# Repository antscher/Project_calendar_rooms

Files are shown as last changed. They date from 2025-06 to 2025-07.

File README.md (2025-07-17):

# Room Calendar Management System

## Project Overview
The Room Calendar Management System is a modern solution for managing meeting room availability using IoT devices. The system combines hardware displays mounted outside each room with a centralized software management platform.

## Project Goals
- Eliminate double-bookings and confusion around room availability
- Provide real-time room status information
- Reduce energy consumption with e-ink displays
- Enable easy room booking directly from the display (by Qr code) or web interface
- Integrate with existing calendar systems

## System Architecture

### Hardware Components
1. **Room Displays**
   - ESP32-S2 microcontroller
   - Waveshare E-ink display
   - Non - Rechargeable battery system
   - QR code for booking

2. **Server Infrastructure**
   - Central management server
   - WiFi network integration

### Software Components
1. **Backend System**
   - Room management
   - Booking system
   - User authentication
   - Calendar integration

2. **Frontend Interfaces**
   - Web dashboard for administrators
   - Display interface for e-ink screens

## Key Features
- Real-time room availability display
- Direct booking from room displays
- Low-power operation with years of battery life
- Calendar synchronization
- Administrative dashboard

## System Illustrations

### Example Screens and Interfaces

#### Calendar Example
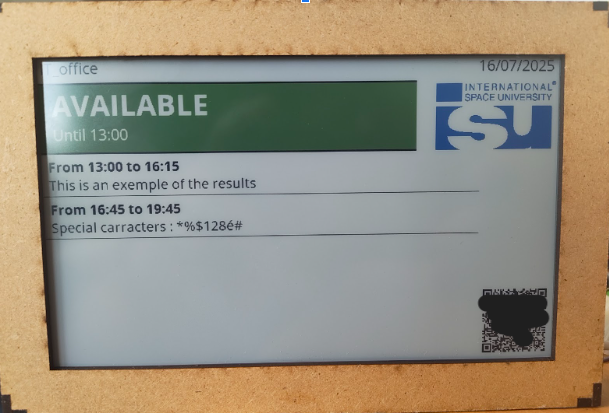
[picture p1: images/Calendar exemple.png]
Calendar Example


#### Reserved Calendar Example
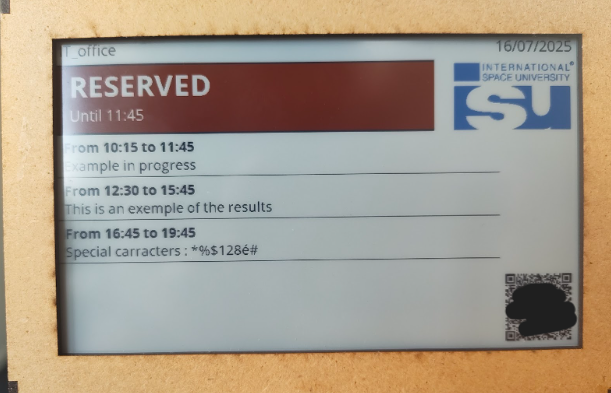
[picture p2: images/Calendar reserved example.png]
Reserved Calendar Example


#### On Air Screen
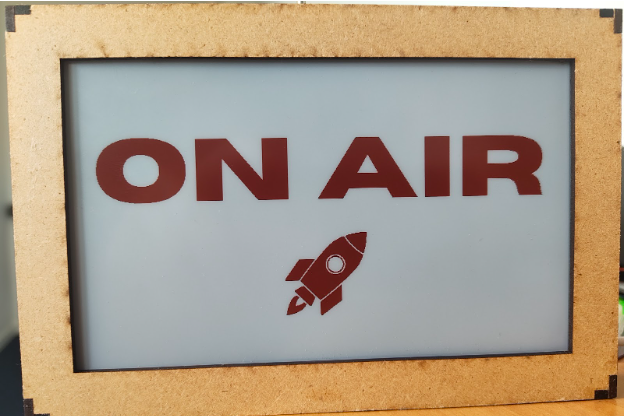
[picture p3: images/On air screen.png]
On Air Screen


#### Mosquitto Server Control
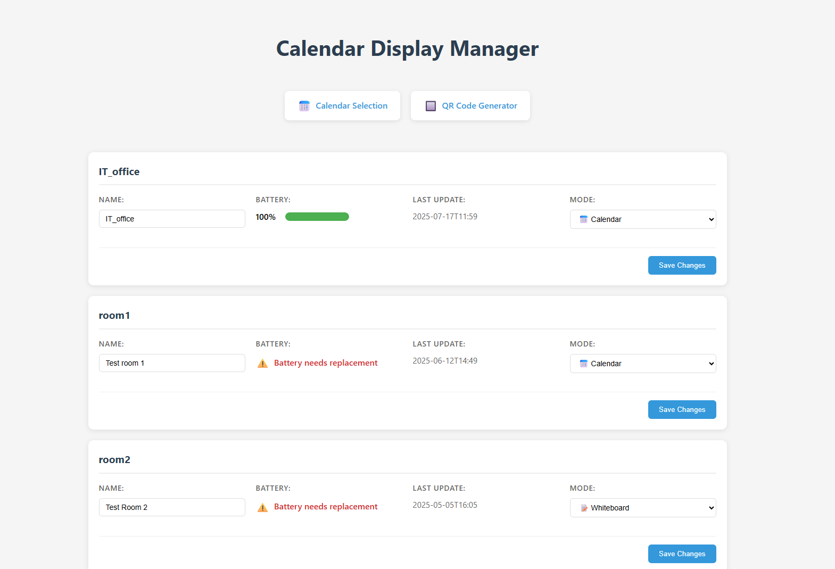
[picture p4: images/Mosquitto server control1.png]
Mosquitto Server Control


## Expected Benefits
- Improved room utilization
- Reduced booking conflicts
- Enhanced user experience
- Energy-efficient operation

## Project Structure
```
Project_calendar_rooms/
├── code_esp32/                      # ESP32 firmware and related tools
|   ├── font2bytes-dynamics/         # Tool for converting fonts to byte arrays
│   └── main/                        # Main ESP32 application code
├── Hardware/                        # Hardware design files
│   ├── cadre room V_.svg/           # Display frame design (version _)
│   ├── Support cadre V_.stl/        # Support of the cadre to be print in 3d (version _)
│   └── esp32 room pcb/              # Custom PCB design for ESP32
└── code_service_server_python/      # Server-side Python applications
    ├── mqtt_service/                # MQTT broker and message handling service
    └── web_local_consol/            # Local web console for room management
```

## License
This project is licensed under GNU GENERAL PUBLIC LICENSE V3 - see the LICENSE.md file for details.

## Main Contributor
This project was developed by Antoine Scherpereel as part of an intership project at ISU (International Space University).

For questions or support, contact:
- Antoine Scherpereel
- Email: antoine.scherpereel@isunet.edu

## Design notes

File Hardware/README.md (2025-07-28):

# Hardware Components Selection

## ESP32-S2 Microcontroller : ESP32-S2 pico from waveshare
Here the link : https://www.waveshare.com/esp32-s2.htm
- **Why this choice?**
  - Built-in WiFi capabilities for network connectivity
  - Low power consumption with deep sleep modes
  - Sufficient GPIO pins for e-ink display interface
  - Cost-effective solution for IoT applications
  - Native USB support for easy programming
  - Enough RAM for rendering the image before displaying it

  Can be power supply between 10V and 1.8V theorically in reality it is needed to be superior to 2.65V

## Waveshare E-Ink Display : Spectra 7.3" from Waveshare
Here the link : https://www.waveshare.com/7.3inch-e-paper-hat-e.htm 
- **Why this choice?**
  - Ultra-low power consumption - only uses power when refreshing
  - Excellent readability in various lighting conditions
  - Maintains display without power
  - Available SPI interface for easy integration with ESP32
  - 6 colors 

## Battery Selection : Roomz display battery
Here the link : https://www.bechtle.com/fr-en/shop/roomz-display-spare-batteries--4329865--p
- **Why not rechargeable Li-primary**
  - High energy density
  - Low self-discharge rate
  - Long cycle life
  - Safe for fire problems

  Normally the battery will stay really close to 3V during all it live cycle but a varation can cause effects.
  Capacity (%)	Voltage (V)
  100%	        3.0 – 3.2 V
  90%	          3.0 – 3.1 V
  80%	          2.95 – 3.1 V
  50%	          2.9 – 3.0 V
  20%	          2.8 – 2.9 V
  10%	          2.7 – 2.8 V
  0%          	~2.0 – 2.5 V

  Note : After testing with different input voltage, the results are : 
  - > 2.65V : work normally
  - between 2.65 and 2.4 : work but risk of losing is SPRAM
  - < 2.4 V : not working at all

  Conclusion : we can use even if we consider there is risk of malfounctionning at the end of life
  (Possibility utilising NVS memory but there is a limit in R/W cycle)

## Power Considerations
- E-ink display only draws power during updates
- ESP32-S2 deep sleep mode < 10µA
- Expected battery life: 2-3 years between replacing battery

## The PCB 

The pcb is made on Kicad
You can open it and modify it with Kicad, may be you will need to downloads some library for footprints
You can purshase it, but you have to first expot in gerber file.
All of the componnent required are in the "Component list.xlsx", you can change some component by similar ones but make sure the footprint is compatible (or modify it).

## The support of the frame

It is made in Fusion 360, you have access to the STL file to print the design.
Use M3 screws to attach it.

## The frame

The frame is made with Inkscape, it is a .svg file.
It is designed for 3mm wood.
It needs to be cut (red lines) and engraved (blue surface).
You need to glue it except the back, which just fits in so you can remove it after.
For the screen, tape it or glue it.

### Frame Images

See the following images for reference:
- Frame closed
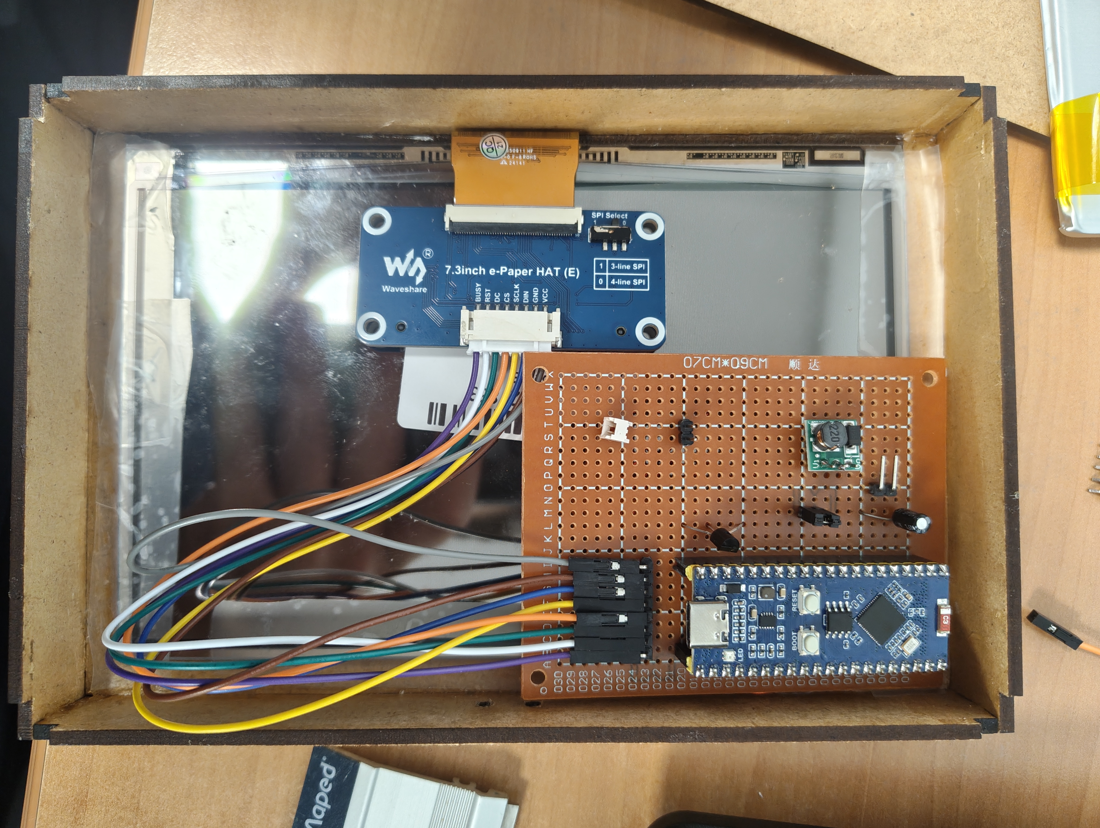
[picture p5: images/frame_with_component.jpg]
Frame component
-

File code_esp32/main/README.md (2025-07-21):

## Overview
An ESP32-based e-paper display system for room availability and scheduling. This system connects to WiFi, communicates via MQTT, and displays room booking information on a Waveshare 7.3" e-Paper display.

## Directory Structure
```
main/
├── src/
│   ├── Config/         # Configuration files
│   ├── e-Paper/       # E-paper display drivers
│   ├── Fonts/         # Font definitions
│   ├── GUI/           # Graphics interface
│   └── Image/         # Image resources
├── calendar.cpp       # Calendar logic implementation
├── calendar.h         # Calendar class definitions
├── interface_graphique.cpp  # Display interface
├── interface_graphique.h    # Display definitions
├── main.ino          # Main program
├── mqtt_communication.ino    # MQTT handling
└── wifi_data.h       # WiFi credentials (to be created)

```
src/ is the library from https://www.waveshare.com/wiki/7.3inch_e-Paper_HAT_(E)_Manual#ESP32.2F8266 -> demo code but it is modified to use dynamics fonts and all of the ASCII characters table

## Setup Instructions

### 1. Create wifi_data.h
Create a new file `/main/wifi_data.h` with your network credentials:

```cpp
#ifndef WIFI_DATA_H
#define WIFI_DATA_H

const char* ssid = "YOUR_WIFI_SSID";
const char* password = "YOUR_WIFI_PASSWORD";
const char* mqtt_broker = "YOUR_MQTT_BROKER_ADDRESS";
const int mqtt_port = 1883;
const String client_id = "esp32-client-XXXX"; 

// Unique client ID
const char* mqtt_username = "YOUR_MQTT_USERNAME";
const char* mqtt_password = "YOUR_MQTT_PASSWORD";
const char* topic = "room/ROOM_NAME";
const char* topic_reponse = "resp_room/ROOM_NAME";

// Variable of referency
const char name_room_const[] = "ROOM_NAME TO DISPLAY";

#endif
```

### 2. Hardware Requirements
- ESP32-S2 microcontroller
- Waveshare 7.3" e-Paper display
- See Hardware/README.md for detailed specifications

### 3. Software Dependencies
Install this librairies if needed 
- Arduino IDE with ESP32 by espressif in the board manage (especially ESP32 S2 Dev Module) (tested v3.2.0)
- Required Libraries:
  - PubSubClient (tested v2.8)
  - WiFi (built in)
  - SPI (built in)

### 4. Building and Flashing
1. Open the project in Arduino IDE
2. Select ESP32-S2 Dev Module board
3. Install required libraries
4. Compile and upload to ESP32 with parameters of esp 32 as : 
- USB CDC on boot : "Enabeled"
- CPU frequency : "160MHz"
- Core debug "None"
- Erase all flash : "Enabeled" (or "Disabled" for saving NVS memory)
- Flash frequency : "40 MHz"
- Flash Mode : "QIO"
- JTAG Adapter : "Disabeled"
- USB Firmware MSC : "Huge APP (3MB No OTA/1 MB SPIFFS)"
- PSRAM : "Enabeled"
- Upload Mode "UART0"
- Upload Speed : "921600"
- Zigbee Mode : "Disabeled"

## Operation Modes
- **Normal Mode**: Displays room availability and upcoming events
- **Night Mode**: Shows logo and enters deep sleep (20:00-7:00)
- **On Air Mode**: Displays "On Air" sign for broadcasting
- **Error Mode**: Handles connection failures

## MQTT Message Format
Messages follow this structure :
- for a calendar
```
cYYYY-MM-DDTHH:MM[Event1 Description]DD,MM,DD,MM,HH,MM,HH,MM[Event2...]
```
- for other  (the first letter is the screen mode)
```
wYYYY-MM-DDTHH:MM
```
First character indicates mode:
- 'c': Calendar mode
- 'w': White screen (or night mode)
- 'o': On Air mode
- 'e': Error
- 'u': Update room name

## Power Management
- Uses deep sleep between updates
- Wakes up for:
  - Scheduled updates
  - Event start/end times
  - Daily morning activation

## Memory Optimization

To maximize battery life and reliability, the ESP32 firmware now uses RTC memory (`RTC_DATA_ATTR`) to store key variables such as `name_room` and `new_day`. This allows the device to retain these values even during deep sleep cycles, minimizing unnecessary writes to flash and saving power.

- `name_room`: The room name is stored in RTC memory and updated only when needed.
- `new_day`: This variable tracks the battery status and is also stored in RTC memory.

### Battery Reset Procedure

To reset the battery status after a replacement or maintenance:
1. Open the Mosquitto MQTT app.
2. Mode reset battery
3. Press "Save" in the app and then refresh .

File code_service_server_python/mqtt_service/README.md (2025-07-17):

# 📡 MQTT Calendar Service

A Python-based MQTT service by **Antscher** that manages communication between ESP32 devices and Google Calendar.

This service handles:
- MQTT broker communication
- Google Calendar integration
- ESP32 device state management
- Screen mode control

---

## 🚀 Features

- 🔄 **MQTT Communication**  
  Handles bi-directional communication with ESP32 devices.

- 📅 **Google Calendar Integration**  
  Fetches and formats calendar events for display.

- 🔋 **Battery Management**  
  Tracks and stores ESP32 device battery status.

- 🖥️ **Screen Mode Control**  
  Manages different display modes (calendar, whiteboard, on air).

---

## ⚙️ Requirements

- Python 3.7+
- paho-mqtt
- google-api-python-client
- oauth2client
- python-dotenv

## 🛠️ Configuration

1. Set up `.env` file with MQTT broker details
2. Configure `credentials.json` for Google Calendar API
3. Ensure `token.json` is present for OAuth2 authentication

### Environment Variables (.env)

Create a `.env` file with the following configuration:

```properties
# MQTT Broker Configuration
USE_LOCAL=false           # Set to true for local broker, false for remote
BROKER_LOCAL=localhost    # Local broker address
BROKER_IP=your.broker.ip  # Remote broker IP/hostname
PORT=1883                 # MQTT broker port
TOPIC=room/#             # Topic pattern to subscribe to
USERMQTT=your_username   # MQTT authentication username
PASSWORD=your_password   # MQTT authentication password
```

- `USE_LOCAL`: Toggle between local and remote broker
- `BROKER_LOCAL`: Address for local MQTT broker
- `BROKER_IP`: Address for remote MQTT broker
- `PORT`: Port number for MQTT connection
- `TOPIC`: MQTT topic pattern for device communication
- `USERMQTT`: Username for MQTT authentication
- `PASSWORD`: Password for MQTT authentication

## 📁 Project Structure

mqtt_service/
│
├── communication_mqtt.py   # Main MQTT handler
├── google_agenda.py       # Google Calendar integration
├── esp_data.py           # ESP device state management
├── credentials.json      # Google API credentials
├── token.json           # OAuth2 tokens
└── .env                 # Environment configuration

## Stockage of data

Every data are stocked on the "esp-data.json". If you want you can manually change the data or the mode by modifying it. I you want to delete a screen you need to remove the line that correspond  directly on the file

## 🔐 Security
- Secure MQTT credentials
- OAuth2 authentication for Google Calendar
- Local JSON storage for device data

## 🧑‍💻 Author
Made with 🧠 by Antscher

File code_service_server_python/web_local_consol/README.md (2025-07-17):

# 🗓️ Room Control Web App

A local Flask web app by **Antscher** to manage and control multiple calendar-enabled display screens in different rooms.

This app allows you to:
- View info
- Set and update room names
- Assign or change screen display modes
- Configure individual calendar URLs
- Generate and display QR codes for easy mobile access

---

## 🚀 Features

- 📺 **Screen Mode Selector**  
  Choose the display mode for each screen (agenda, standby, status…).

- 🏷️ **Custom Room Names**  
  Easily rename rooms via the web interface.

- 🔗 **Calendar URL Configuration**  
  Assign custom ICS / Google Calendar URLs to each room for event syncing.

- 📱 **QR Code Generator**  
  Automatically generate a QR code for arduino in C++

- 💾 **Data Persistence**  
  All configurations are stored in a JSON file (`esp_data.json`) for consistent behavior after reboot.

---

## ⚙️ Requirements

- Python 3.7+
- Flask
- qrcode
- Pillow

## 🛠️ How It Works
Launch the app:
python app.py

Access the local web interface at:
http://localhost:5000

## 📁 Project Structure

project/
│
├── app.py                 # Main Flask app, entry point for the web server
├── esp_data.json          # JSON database of all ESP screen data and configuration
├── qr_code_generator/     # Python scripts for generating QR codes for ESP devices
│   ├── generate_qr.py     # Main QR code generation script
│   └── ...                # Other helper scripts
├── templates/             # HTML templates for Flask (Jinja2)
│   ├── index.html         # Main dashboard page
│   ├── room_config.html   # Room configuration page
│   └── ...                # Other template files
├── tmp/                   # Temporary storage for generated C++ files and QR images
│   └── ...                # Files created during runtime
└── static/                # Static assets (JavaScript, CSS, images)
    ├── style.css          # Main stylesheet
    ├── script.js          # Main JavaScript file
    └── ...                # Other static files

# Web Local Console

A Flask web application for managing ESP device configurations and calendars.

## Setup

1. Install required packages:
```bash
pip install flask python-dotenv
```

2. Create a `.env` file in the project root with the following variables:
If it don't works, just rename the variable in the script "app.py"
```
USERNAME=your_username
PASSWORD=your_password
DATA_FILE=/path/to/esp_data.json
FLASK_HOST=0.0.0.0
FLASK_PORT=5000
```

## Environment Variables

- `USERNAME`: Authentication username for accessing the web interface
- `PASSWORD`: Authentication password for accessing the web interface
- `DATA_FILE`: Path to the JSON file storing ESP device data
- `FLASK_HOST`: Host address for the Flask server (default: 0.0.0.0)
- `FLASK_PORT`: Port number for the Flask server (default: 5000)

## Running the Application

Start the server:
```bash
python app.py
```

The web interface will be available at `http://<FLASK_HOST>:<FLASK_PORT>`

## Features

- ESP device management and status monitoring
- Calendar configuration and QR code generation
- Basic authentication for secure access

## 🧑‍💻 Author
Made with 🧠 by Antscher

---

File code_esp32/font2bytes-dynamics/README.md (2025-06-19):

# font2bytes (Modified Version)

Python script to create custom fonts for Waveshare e-Paper / e-Ink (ESP32 module)

---

## 📌 About This Fork

This is a modified version of the original [font2bytes](https://github.com/TheHeXstyle/font2bytes) project by [TheHeXstyle](https://github.com/TheHeXstyle), licensed under **LGPL v3.0**.

My contribution introduces **dynamic character widths**:  
🔠 Each character now has its own **individual width** depending on its actual pixel width, instead of a fixed-size grid. This allows more compact and proportional text rendering on e-paper displays.
🔠 Also now all the ASCII characters are implemented (exemple : @)

However, you have to also modify the library of waveshare (there is an example in main in src of this repo)

---

## 🎯 Motivation

The Waveshare ESP32 library only offers a few basic fixed-width fonts (`font8`, `font12`, `font16`, `font20`, `font24`). This is very limiting for UI design or text-heavy applications.

This script helps generate **custom variable-width fonts** using any TrueType font (`.ttf`), with complete control over size and style.

---

## 🧰 Requirements

- Python 3
- [Pillow](https://pillow.readthedocs.io/en/stable/index.html)
- [numpy](https://numpy.org/install/)

> 💡 **Note:** Pillow and PIL cannot co-exist in the same environment. Please uninstall `PIL` before installing `Pillow`.

---

## 🛠️ How to Use

1. Drop any font you want to use (`.ttf`) inside the `./fonts` folder.

2. In `font2bytes.py`, configure:
   - A name for your new font output file
   - The `.ttf` font name you want to use (default: `Roboto-Regular`)
   - The desired height of characters (width is dynamic)

3. Run the script:

   ```bash
   python font2bytes.py

The python script will generate the new .cpp file within the ./output folder with the desired name

within the waveshare library source folder (Arduino\libraries\esp32-waveshare-epd\src)

4. add the new .cpp font file

5. open the fonts.h and

6. add a new "extern" line with the name of the new font

    E.g.: extern sFONT FontBold40;

7. Use the new font in your script and enjoy!

    E.g. Paint_DrawString_EN(5, 0, "waveshare Electronics", &FontBold40, BLACK, WHITE);

Examples
-------------------
within the ./output folder there are already a couple of .cpp files that can be used without running the oython code.
Just follow the instructions from the 6th step

Author
-------------------
Original version by TheHeXstyle

Modified and extended by Antscher to support dynamic character widths

License
-------------------
LGPL v3.0, see LICENSE for details.

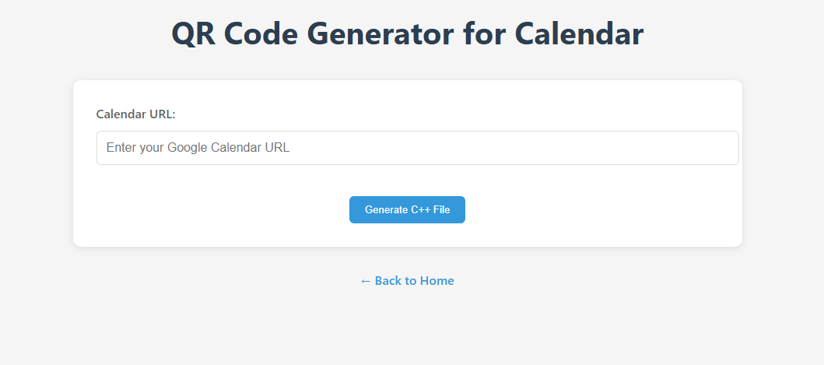
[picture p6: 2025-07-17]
images/Mosquitto server control3.png

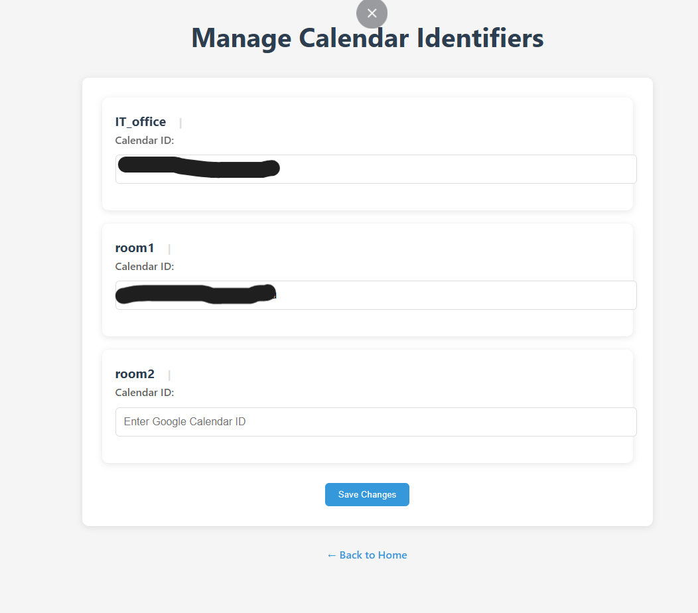
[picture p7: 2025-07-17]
images/Mosquitto server control2.png

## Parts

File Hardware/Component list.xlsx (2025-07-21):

PCB part
Item # | *Designator | *Qty | Manufacturer | *Mfg Part # | Description / Value | *Package/Footprint | Mounting Type | Your Instructions / Notes | *Unit Price(5 sets) | *Total | *Delivery Time | *Actual Purchase Mfg Part # | Customer Reply | PCBWay Update
1 | ESP32S2L1, ESP32S2L2 | 2 | Harwin | M20-7862042 | 20-pin 2.54 mm vertical pin socket | Connector_PinSocket_2.54mm:PinSocket_1x20_P2.54mm_Vertical | SMD | Right & left pin rows for ESP32S2 module | $1.992 | $19.920
2 | J1 | 1 | Harwin (or generic) | PTV1R-08-G-D-K | 8-pin 2.54 mm horizontal pin header | Connector_PinHeader_2.54mm:PinHeader_1x08_P2.54mm_Horizontal | THT | Use PTV1R-08-G (Harwin) or similar quality header | $0.843 | $4.215 |  | M20-9960845
3 | J2 | 1 | Molex (JST equivalent) | 5352 (PH series) or 53048-0210 | 2-pos 1.25 mm PicoBlade right-angle header (battery Conn) | Connector_JST:PicoBlade_53048-0210_1x02_P1.25mm_Horizontal | THT | For battery connector — use Molex 53048-0210 | $0.409 | $2.045 |  | 53048-0210
4 | Q1 | 1 | Alpha & Omega Semiconductors | AO3400A | 30 V N‑Channel MOSFET, SOT‑23 | SOT-23-3 | SMD |  | $0.121 | $0.605
5 | SW1 | 1 | Würth Elektronik | 450301014042 | Slide switch SPDT 500 mA / 12 V, red actuator | Button_Switch_THT:WS-SLTV THT | THT | Use WS‑SLTV series; datasheet | $0.596 | $2.980 |  | SLW-864574-5A-RA-N-D
6 | C1,C2 | 1 | Murata Electronics | GRM21BR61C106KE15K | Capacitor 10uF | C_0805_2012Metric | SMD
7 | L1 | 1 | BOURNS | SRR1260-100M | Inductance 10uH | SRR1260-100M | SMD
7 | L2 | 1 | ANALOG DEVICES | MAX1724EZK50+T | Regulator DC/DC 5V | MAX1724EZK50+T | SMD

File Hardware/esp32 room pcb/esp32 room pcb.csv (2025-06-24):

Reference | Qty | Value | DNP | Exclude from BOM | Exclude from Board | Footprint | Datasheet
ESP32S2L1 | 1 | Left pins |  |  |  | Connector_PinSocket_2.54mm:PinSocket_1x20_P2.54mm_Vertical | ~
Esp32S2L2 | 1 | Right pins |  |  |  | Connector_PinSocket_2.54mm:PinSocket_1x20_P2.54mm_Vertical | ~
J1 | 1 | DISPLAY connector |  |  |  | Connector_PinHeader_2.54mm:PinHeader_1x08_P2.54mm_Horizontal | ~
J2 | 1 | BATTERY connector |  |  |  | Connector_JST:JST_PH_S2B-PH-SM4-TB_1x02-1MP_P2.00mm_Horizontal | ~
Q1 | 1 | AO3400A |  |  |  | Package_TO_SOT_SMD:SOT-23 | http://www.aosmd.com/pdfs/datasheet/AO3400A.pdf
SW1 | 1 | SW_Wuerth_450301014042 |  |  |  | Button_Switch_THT:SW_Slide-03_Wuerth-WS-SLTV_10x2.5x6.4_P2.54mm | https://www.we-online.com/components/products/datasheet/450301014042.pdf

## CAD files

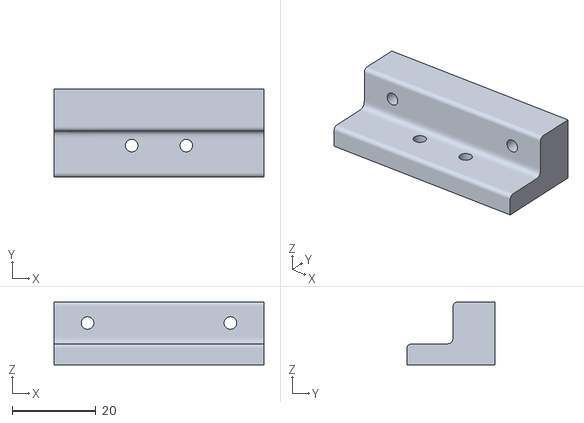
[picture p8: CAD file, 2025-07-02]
Hardware/support cadre V2 v2.stl
50.0 x 21.0 x 15.0

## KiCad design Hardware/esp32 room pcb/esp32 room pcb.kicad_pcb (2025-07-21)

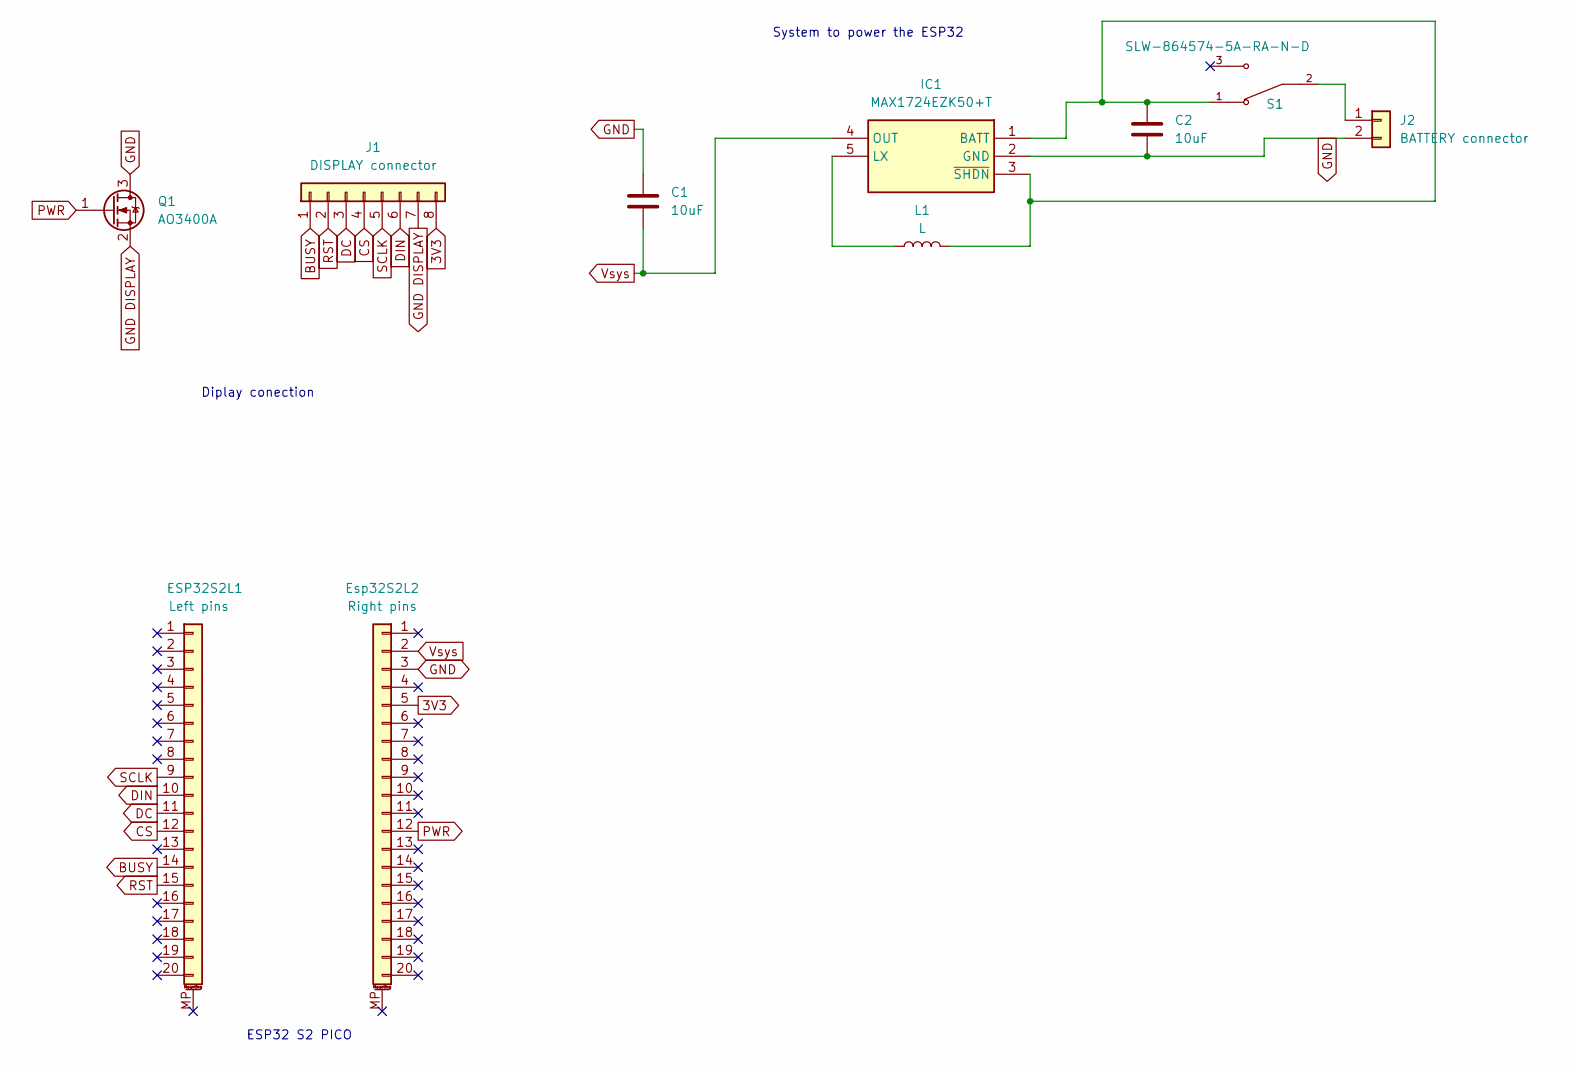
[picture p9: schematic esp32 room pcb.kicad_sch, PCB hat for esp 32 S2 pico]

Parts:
C1, C2: 10uF; C_0805_2012Metric
ESP32S2L1: Left pins; PinSocket_1x20_P2.54mm_Vertical
Esp32S2L2: Right pins; PinSocket_1x20_P2.54mm_Vertical
IC1: MAX1724EZK50+T; SOT95P275X110-5N; Mouser Part Number 700-MAX1724EZK50T
J1: DISPLAY connector; PinHeader_1x08_P2.54mm_Horizontal
J2: BATTERY connector; JST_PH_S2B-PH-SM4-TB_1x02-1MP_P2.00mm_Horizontal
L1: L; SRR1260100M
Q1: AO3400A; SOT-23
S1: SLW-864574-5A-RA-N-D; SW_SLW-864574-5A-RA-N-D; PARTREV 1.01

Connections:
3V3: Esp32S2L2.5, J1.8
BUSY: ESP32S2L1.14, J1.1
CS: ESP32S2L1.12, J1.4
DC: ESP32S2L1.11, J1.3
DIN: ESP32S2L1.10, J1.6
GND: C1.1, C2.2, Esp32S2L2.3, IC1.2 (GND), J2.2, Q1.3 (D)
GND DISPLAY: J1.7, Q1.2 (S)
unnamed: C2.1, IC1.1 (BATT), IC1.3 (~SHDN), L1.2, S1.1
unnamed: IC1.5 (LX), L1.1
unnamed: J2.1, S1.2
PWR: Esp32S2L2.12, Q1.1 (G)
RST: ESP32S2L1.15, J1.2
SCLK: ESP32S2L1.9, J1.5
Vsys: C1.2, Esp32S2L2.2, IC1.4 (OUT)

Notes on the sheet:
System to power the ESP32
Diplay conection
ESP32 S2 PICO

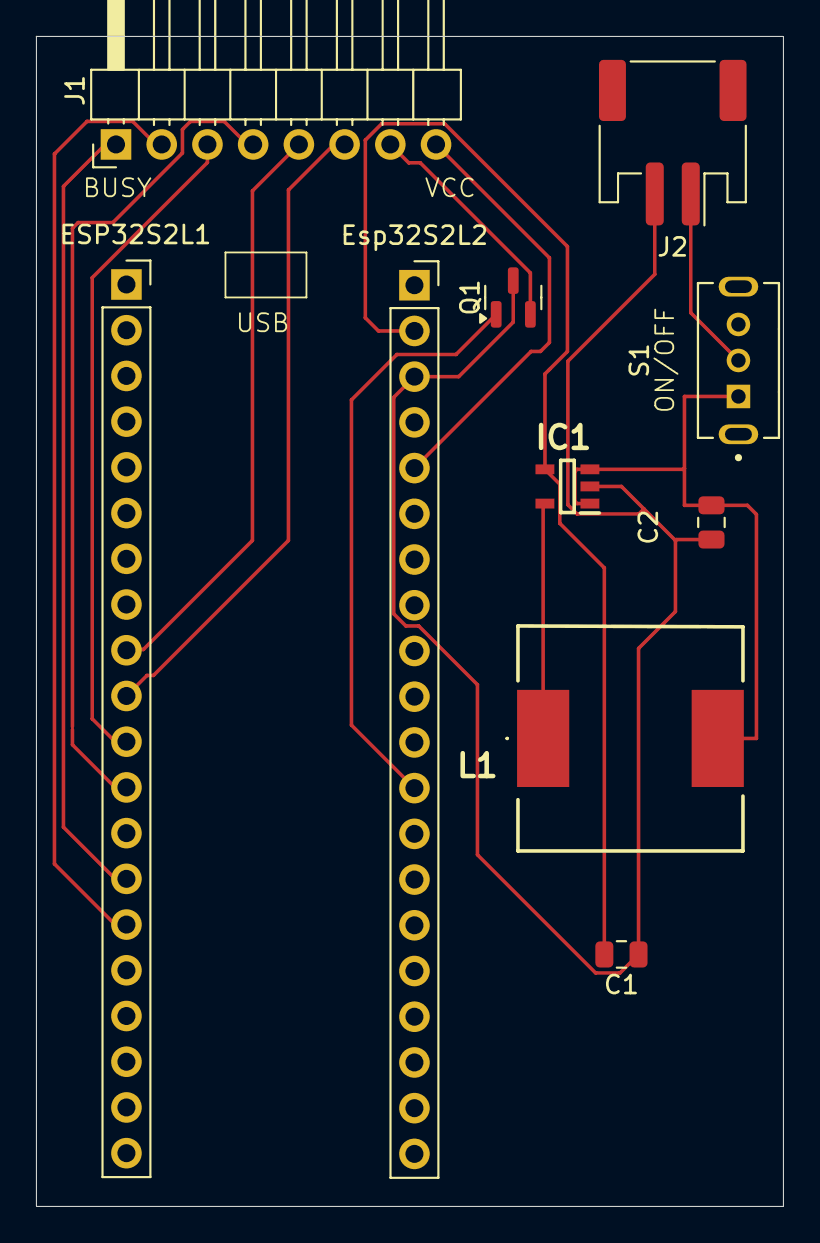
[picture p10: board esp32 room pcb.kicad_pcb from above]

Board: 2 copper layers, 41.5 x 65.0 mm, 10 parts (0 on the bottom side), 14 nets.

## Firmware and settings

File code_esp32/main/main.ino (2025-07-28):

#include <calendar.h>
#include "interface_graphique.h"
#include "optimization_config.h"
#include "nvs_flash.h"
#include "nvs.h"


#define uS_TO_MIN_FACTOR 60000000ULL
RTC_DATA_ATTR char new_day;
RTC_DATA_ATTR unsigned long long int night_time;
extern RTC_DATA_ATTR char name_room[64];
extern RTC_DATA_ATTR char old_message[512];
extern const char name_room_const[];

void setup() {
  delay(700); // Wait for voltage to stabilize
  Serial.begin(115200);
  Serial.println("Boot OK");
  check_rtc_data();

  if (night_time > 0) {
    Serial.print("Night time : ");
    Serial.println(night_time);
    if (new_day != '0'){
      new_day = '0';
    }
    if (night_time > 30) {
      night_time -= 30;
      Serial.println(night_time);
      esp_sleep_enable_timer_wakeup(uS_TO_MIN_FACTOR*30);
    }
    else {
      esp_sleep_enable_timer_wakeup(uS_TO_MIN_FACTOR*night_time);
      night_time = 0;      
    }

    Serial.println("Entering Deep Sleep mode");
    // ESP32 goes to deep sleep
    esp_deep_sleep_start();
  }

  String message =  mqtt_calendar(new_day); 

  char action = message[0];
  char date_buffer[64];
  calendar_string_i(message, 0, date_buffer, sizeof(date_buffer));
  Now actual_date(date_buffer);
  int time_to_sleep = actual_date.timeToSleep();

  if (action == 'c'){
    char event_buffer[256];
    calendar_string_i(message, 1, event_buffer, sizeof(event_buffer));
    CalendarEvent calendar1(event_buffer);
    //definition of time to sleep, depend if there is an event soon
    time_to_sleep = actual_date.timeToSleep(calendar1);
  }


  if (actual_date.nightMode()){
    // Night mode
    action = 'w';
    message[0] = 'w';
    night_time = time_to_sleep - 15;
    time_to_sleep = 30;
    new_day = '1';
  }
  

  else if (checkAndUpdateMessage(message)){
    // Nothing to do
    action = 'n';
  }
  switch (action) {
    case 'c' : { // Calendar mode
      nvs_flash_init();
      load_name_room_from_flash();
      DEV_Delay_ms(100);
      Serial.println("Initialization and clear");
      init_and_clear();

      Serial.println("Displaying calendar");

      char event_buffer1[256], event_buffer2[256], event_buffer3[256], event_buffer4[256], event_buffer5[256];
      calendar_string_i(message, 1, event_buffer1, sizeof(event_buffer1));
      calendar_string_i(message, 2, event_buffer2, sizeof(event_buffer2));
      calendar_string_i(message, 3, event_buffer3, sizeof(event_buffer3));
      calendar_string_i(message, 4, event_buffer4, sizeof(event_buffer4));
      calendar_string_i(message, 5, event_buffer5, sizeof(event_buffer5));

      CalendarEvent calendar1(event_buffer1);
      CalendarEvent calendar2(event_buffer2);
      CalendarEvent calendar3(event_buffer3);
      CalendarEvent calendar4(event_buffer4);
      CalendarEvent calendar5(event_buffer5);

      display_calendar(actual_date,calendar1,calendar2,calendar3,calendar4,calendar5);

      Serial.println("Clear and close");
      clear_and_close();
      

    break; }

    case 'w' : { // White screen mode (night)
      Serial.println("Displaying white screen");
      DEV_Delay_ms(100);
      init_and_clear();
      display_sleep();
      clear_and_close();
      
    break; }

    case 'o' : { // On Air mode
      Serial.println("Displaying On Air screen");
      DEV_Delay_ms(100);
      init_and_clear();
      display_OnAir();
      clear_and_close();
      
    break; }

    case 'e' :  { // Error with MQTT message
      Serial.println("MQTT Error");
      // Try to reconnect to the server after 5 min
      time_to_sleep = 5;
      
    break;  }  

    case 'u' :{ // Update the room name
      Serial.println("Update name");
      char name_buffer[64];
      calendar_string_i(message, 1, name_buffer, sizeof(name_buffer));
      strncpy(name_room, name_buffer, sizeof(name_room) - 1);
      name_room[sizeof(name_room) - 1] = '\0';  // Ensure string is null-terminated
      save_name_room_to_flash();
      time_to_sleep = 1;
      delay(100);

    break;  }

    case 'n' :{ // Nothing to do
      Serial.println("Nothing to do");
    break;}
  }

  Serial.print("Time to sleep ");
  Serial.println(time_to_sleep);
  delay(100);
  // ESP32 sleeps in deep mode (it will never enter the loop function)
  esp_sleep_enable_timer_wakeup(uS_TO_MIN_FACTOR*time_to_sleep);
  Serial.println("Entering Deep Sleep mode");

  // ESP32 goes to deep sleep
  esp_deep_sleep_start();
  Serial.println("This message will not be displayed, because the ESP32 is in Deep Sleep!");

}

void loop() {
  // Main code here, runs repeatedly (not used, ESP32 sleeps)
  delay(5000);
}


void check_rtc_data() {
    Serial.println("Check");
    // Check new_day value
    if (new_day != '0' && new_day != '1' && new_day != '2') {
        Serial.println("RTC new_day invalid -> reset to '0'");
        new_day = '0';
    }

    // Check night_time (example: max coherent time)
    if (night_time > 2880ULL ) {  // 2 days in minutes, adjustable
        Serial.println("RTC night_time incoherent -> reset");
        night_time = 0;
    }

    // Check old_message
    if (old_message[0] == '\0') {
        Serial.println("RTC old_message empty -> initialize to empty string");
        old_message[0] = '\0';
    }
}

void save_name_room_to_flash() {
    nvs_handle_t my_handle;
    esp_err_t err = nvs_open("storage", NVS_READWRITE, &my_handle);
    if (err == ESP_OK) {
        nvs_set_str(my_handle, "name_room", name_room);
        nvs_commit(my_handle);
        nvs_close(my_handle);
        Serial.println("name_room saved to flash");
    } else {
        Serial.println("NVS save error");
    }
}

void load_name_room_from_flash() {
    nvs_handle_t my_handle;
    esp_err_t err = nvs_open("storage", NVS_READONLY, &my_handle);
    if (err == ESP_OK) {
        size_t required_size = sizeof(name_room);
        err = nvs_get_str(my_handle, "name_room", name_room, &required_size);
        if (err == ESP_OK) {
            Serial.print("name_room loaded: ");
            Serial.println(name_room);
        } else {
            Serial.println("No saved data -> initializing with default");
            strncpy(name_room, name_room_const, sizeof(name_room));
        }
        nvs_close(my_handle);
    } else {
        Serial.println("NVS load error");
    }
}

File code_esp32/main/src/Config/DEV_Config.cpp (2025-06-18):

/*****************************************************************************
* | File      	:   DEV_Config.c
* | Author      :   Waveshare team
* | Function    :   Hardware underlying interface
* | Info        :
*----------------
* |	This version:   V1.0
* | Date        :   2020-02-19
* | Info        :
#
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
******************************************************************************/
#include "DEV_Config.h"

void GPIO_Config(void)
{
    pinMode(EPD_BUSY_PIN,  INPUT);
    pinMode(EPD_RST_PIN , OUTPUT);
    pinMode(EPD_DC_PIN  , OUTPUT);
    pinMode(EPD_PWR_PIN  , OUTPUT);
    pinMode(EPD_CS_PIN , OUTPUT);

    digitalWrite(EPD_PWR_PIN , HIGH);
    digitalWrite(EPD_CS_PIN , HIGH);
}

void GPIO_Mode(UWORD GPIO_Pin, UWORD Mode)
{
    if(Mode == 0) {
        pinMode(GPIO_Pin , INPUT);
	} else {
		pinMode(GPIO_Pin , OUTPUT);
	}
}
/******************************************************************************
function:	Module Initialize, the BCM2835 library and initialize the pins, SPI protocol
parameter:
Info:
******************************************************************************/
UBYTE DEV_Module_Init(void)
{
	//gpio
	GPIO_Config();

	//serial printf
	Serial.begin(115200);
    Serial.println("Initialisation");
	// spi
	SPI.begin(EPD_SCK_PIN, -1 /*MISO non utilisé*/, EPD_MOSI_PIN, EPD_CS_PIN);
    SPI.beginTransaction(SPISettings(4000000, MSBFIRST, SPI_MODE0));

	return 0;
}


void DEV_GPIO_Init(void)
{
    SPI.end(); 
    pinMode(EPD_SCK_PIN, OUTPUT);
    pinMode(EPD_MOSI_PIN, OUTPUT);
}

void DEV_SPI_Init(void)
{
    SPI.begin();
    SPI.beginTransaction(SPISettings(4000000, MSBFIRST, SPI_MODE0));
}


/******************************************************************************
function:
			SPI read and write
******************************************************************************/
void DEV_SPI_WriteByte(UBYTE data)
{
    SPI.transfer(data);
}

void DEV_SPI_Write_nByte(UBYTE *pData, UDOUBLE len)
{
    for (int i = 0; i < len; i++)
        DEV_SPI_WriteByte(pData[i]);
}

void DEV_SPI_SendByte(UBYTE data)
{
    GPIO_Mode(EPD_MOSI_PIN, OUTPUT);
    digitalWrite(EPD_CS_PIN, GPIO_PIN_RESET);
    for (int i = 0; i < 8; i++)
    {
        if ((data & 0x80) == 0) digitalWrite(EPD_MOSI_PIN, GPIO_PIN_RESET); 
        else                    digitalWrite(EPD_MOSI_PIN, GPIO_PIN_SET);

        data <<= 1;
        digitalWrite(EPD_SCK_PIN, GPIO_PIN_SET);     
        digitalWrite(EPD_SCK_PIN, GPIO_PIN_RESET);
    }
    digitalWrite(EPD_CS_PIN, GPIO_PIN_SET);
}

UBYTE DEV_SPI_ReadByte()
{
    UBYTE j=0xff;
    GPIO_Mode(EPD_MOSI_PIN, INPUT);
    digitalWrite(EPD_CS_PIN, GPIO_PIN_RESET);
    for (int i = 0; i < 8; i++)
    {
        j = j << 1;
        if (digitalRead(EPD_MOSI_PIN))  j = j | 0x01;
        else                            j = j & 0xfe;
        
        digitalWrite(EPD_SCK_PIN, GPIO_PIN_SET);     
        digitalWrite(EPD_SCK_PIN, GPIO_PIN_RESET);
    }
    digitalWrite(EPD_CS_PIN, GPIO_PIN_SET);
    GPIO_Mode(EPD_MOSI_PIN, 1);
    return j;
}




void DEV_Module_Exit(void)
{
    digitalWrite(EPD_PWR_PIN , LOW);
}

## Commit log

2025-06-20 modification of foot print for battery connector
    [esp32 room pcb.kicad_pcb]
2025-06-24 ajout des tros pour le cadre
    [esp32 room pcb.csv]
2025-06-26 modification of the switch to a cheaper on
    [esp32 room pcb.kicad_pcb, esp32 room pcb.kicad_sch]
2025-06-26 modification du Readme de hardware
2025-07-01 corection et modification des bugs du à la basse tension (PCB + Arduino)
    [esp32 room pcb.kicad_pcb, esp32 room pcb.kicad_sch]
2025-07-02 correction des bugs de mises à jour et update du Readme
    [main.ino, mqtt_comunication.ino]
2025-07-02 add of the stl for support
    [support cadre V2 v2.stl]
2025-07-16 modification of README
    [Component lists.xls]
2025-07-21 ajout d'un booster 5V pcb
    [Component list.xlsx, Component lists.xls, esp32 room pcb.kicad_pcb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]
